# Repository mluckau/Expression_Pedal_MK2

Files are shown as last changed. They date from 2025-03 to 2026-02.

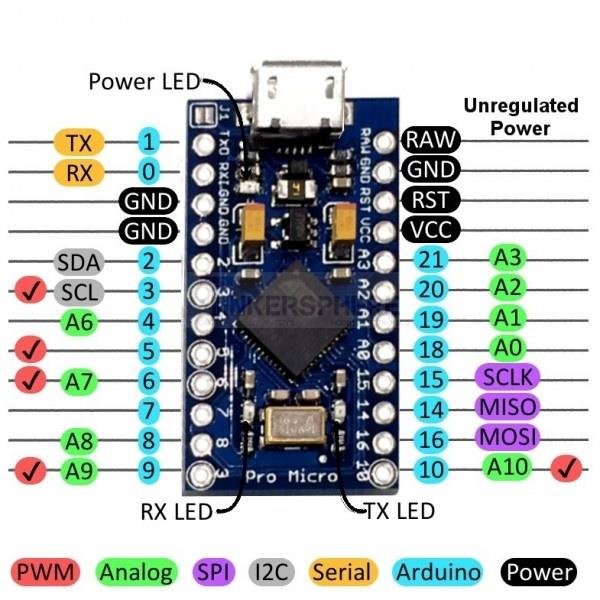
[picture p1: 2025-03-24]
Expression Pedal USB-Adapter/Arduino-Pro-Micro-connections-pinouts.png

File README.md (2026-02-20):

# Expression Pedal MK2 – USB-MIDI Adapter

Ein hochpräziser, zweikanaliger USB-MIDI-Adapter für Expression-Pedale, basierend auf dem Arduino Pro Micro (ATmega32U4). Er wandelt analoge Widerstandswerte herkömmlicher Expression-Pedale in MIDI-Control-Change (CC) Befehle um.

## Features
* **Dual Channel:** Unterstützt zwei unabhängige Expression-Pedale.
* **Plug & Play:** Wird als Standard MIDI-Gerät ("InkoTech Exp MK1") erkannt.
* **Auto-Kalibrierung:** Lernt automatisch den Bewegungsbereich des Pedals.
* **EEPROM-Speicher:** Behält die Kalibrierung auch nach dem Ausstecken bei.
* **Präzisions-Filter:** EMA-Filterung und Hysterese eliminieren Jitter und "Zappeln" der MIDI-Werte komplett.
* **Hardware-Erkennung:** Automatische Erkennung, ob ein Pedal eingesteckt ist (via Schaltbuchsen).
* **Status-LED:** Visuelles Feedback über die Onboard-TX-LED bei MIDI-Aktivität.

## Hardware & Stückliste (BOM)
| Komponente | Anzahl | Beschreibung |
| :--- | :--- | :--- |
| **Arduino Pro Micro** | 1 | ATmega32U4 (5V/16MHz) mit USB-C |
| **Klinkenbuchse 6,35mm** | 2 | TRS (Stereo) mit Schaltkontakt (z.B. REAN NYS216G) |
| **Gehäuse** | 1 | 3D-gedruckt (siehe `Gehäuse/` Ordner) |
| **USB-C Kabel** | 1 | Zur Verbindung mit dem PC |

## Schaltplan (Pinbelegung)
Die Verdrahtung erfolgt direkt am Arduino Pro Micro:

### Expression Pedal 1 (TRS Buchse)
* **Sleeve (S):** GND
* **Ring (R):** 5V (VCC)
* **Tip (T):** Pin **A0** (Wiper des Potis)
* **Schaltkontakt:** Pin **5** (Zieht Pin auf HIGH/LOW zur Erkennung)

### Expression Pedal 2 (TRS Buchse)
* **Sleeve (S):** GND
* **Ring (R):** 5V (VCC)
* **Tip (T):** Pin **A2** (Wiper des Potis)
* **Schaltkontakt:** Pin **6** (Zieht Pin auf HIGH/LOW zur Erkennung)

## Software-Konfiguration
Das Projekt wird mit **PlatformIO** verwaltet.

### Wichtige Parameter in `src/main.cpp`:
* `ALPHA`: Glättungsfaktor (Standard: 0.15). Niedriger = glatter, Höher = schneller.
* `DEADZONE`: Puffer an den Endpunkten (Standard: 15), um sicher 0 und 127 zu erreichen.
* `HYSTERESIS`: Verhindert das Springen zwischen zwei MIDI-Werten (Standard: 0.6).
* `#define DEBUG`: Einkommentieren für Testausgaben im Seriellen Monitor (115200 Baud).

## Bedienung & Kalibrierung
1. Schließe den Adapter an den PC an.
2. Stecke dein Expression-Pedal ein.
3. **Erste Benutzung:** Bewege das Pedal einmal komplett von Anschlag zu Anschlag (Heel to Toe).
4. Der Adapter speichert diese Werte nach 30 Sekunden Stabilität im EEPROM.
5. In deiner DAW (Bitwig, Reaper, etc.) den "InkoTech Exp MK1" auswählen und per "MIDI Learn" zuweisen.

## Lizenz
Dieses Projekt ist Open Source. Viel Spaß beim Nachbauen!

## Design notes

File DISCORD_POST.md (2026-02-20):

# Expression-Pedal-Adapter MK2: DIY USB-MIDI Interface (Dual-Channel)

Moin Leute! 👋

Ich wollte euch mal mein neuestes DIY-Projekt vorstellen: Ein **Expression-Pedal-Adapter**, der herkömmliche analoge Pedale in hochpräzise USB-MIDI Controller verwandelt.

### Warum das Ganze?
Die meisten kommerziellen Adapter sind entweder zu teuer, nur einkanalig oder haben Probleme mit "zappelnden" MIDI-Werten (Jitter). Da ich zwei Pedale nutze, musste eine eigene Lösung her!

### Die Highlights (Features):
* **Dual-Channel:** Ich habe zwei Stereo-Klinkenbuchsen verbaut, man kann also zwei Pedale gleichzeitig nutzen (z.B. Wah-Wah und Volume).
* **Auto-Kalibrierung:** Kein mühsames Eintippen von Min/Max-Werten im Code. Einmal das Pedal komplett bewegen, fertig!
* **EEPROM-Gedächtnis:** Die Kalibrierung wird gespeichert. Einmal eingestellt, bleibt sie auch nach dem Ausstecken erhalten.
* **EMA-Filter & Hysterese:** Ich habe einen exponentiellen Filter eingebaut, der das analoge Rauschen der Potis komplett eliminiert. Die MIDI-Werte sind absolut stabil.
* **Hardware-Erkennung:** Das Gerät erkennt automatisch, ob ein Pedal eingesteckt ist (via Schaltkontakt in der Buchse).

### Die Technik:
* **Controller:** Arduino Pro Micro (ATmega32U4) für native USB-MIDI Unterstützung.
* **Gehäuse:** 3D-gedruckt (FreeCAD Design), kompakt und stabil.
* **Code:** Objektorientiertes C++ mit PlatformIO.

### Was ich gelernt habe:
Besonders knifflig war das "Übersprechen" (Crosstalk) zwischen den analogen Eingängen des Arduinos. Ich habe das im Code durch einen "Double-Reading-Fix" gelöst, jetzt sind die Kanäle komplett isoliert.

Ich bin mit dem Ergebnis super zufrieden, die Latenz ist minimal und es fühlt sich in der DAW (Bitwig Studio / Manjaro Linux) richtig "snappy" an.

Falls jemand Interesse am Nachbau hat oder Fragen zum Code/Schaltplan hat, haut einfach in die Tasten! 🎸🎹

[Link zum GitHub Repository / Bilder / Video - Platzhalter]

Beste Grüße,
Michael

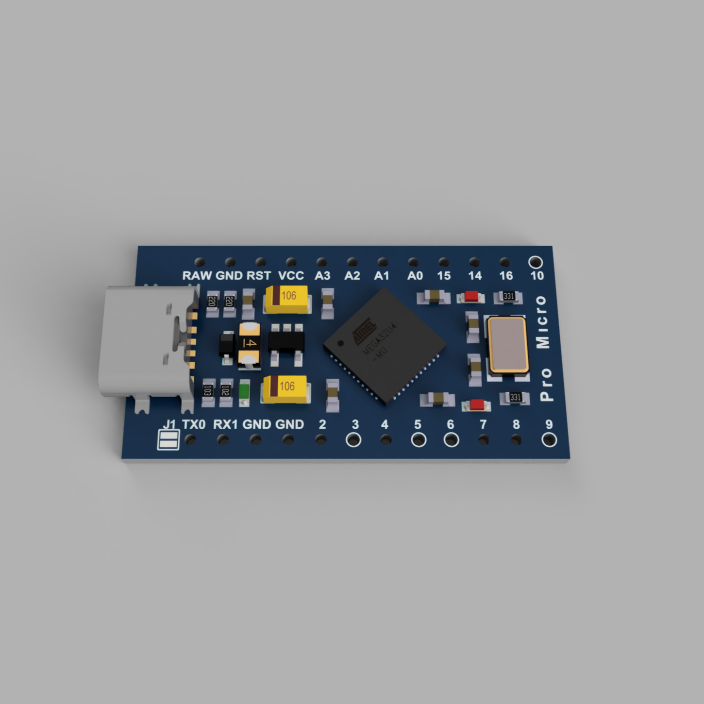
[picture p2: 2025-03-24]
Gehäuse/Models/Arduino_Pro_Micro_USB_Type_C_v1_2023-Jun-13_05-59-24PM-000_CustomizedView47374011633.png

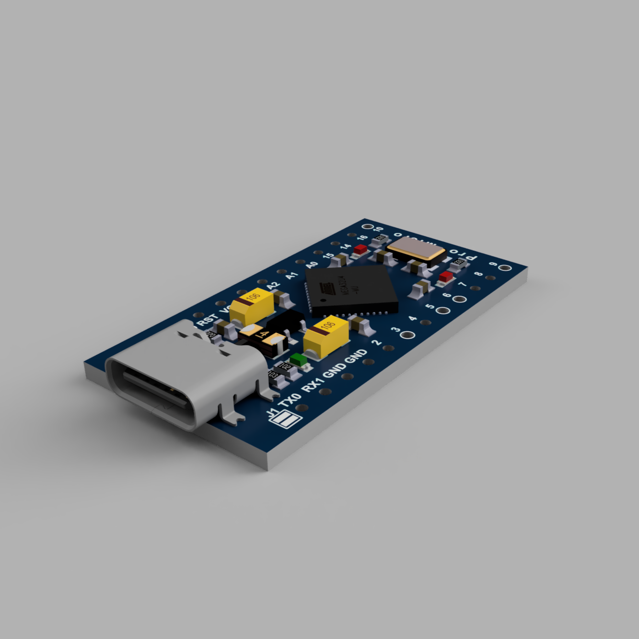
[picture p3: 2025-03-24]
Gehäuse/Models/Arduino_Pro_Micro_USB_Type_C_v1_2023-Jun-13_05-58-19PM-000_CustomizedView2097057146.png

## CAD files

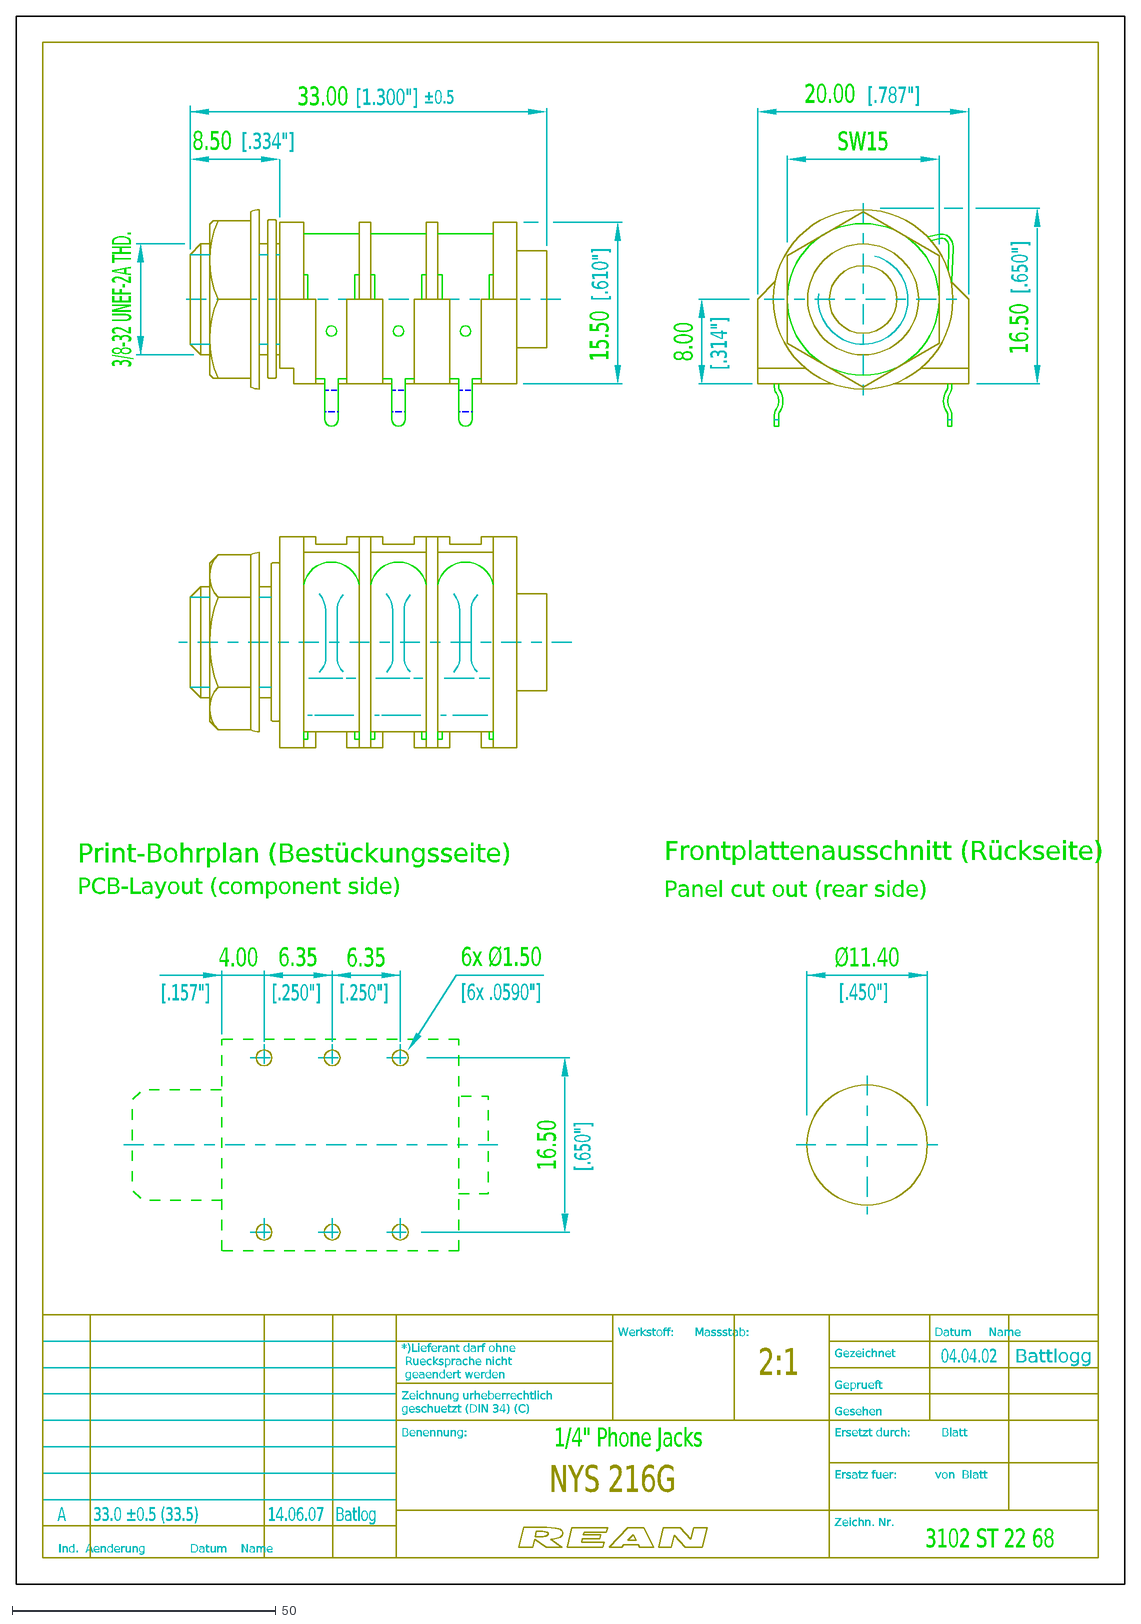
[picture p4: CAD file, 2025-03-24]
Expression Pedal USB-Adapter/nys-216g-1.dxf
Print-Bohrplan (Bestückungsseite)
PCB-Layout (component side)
4.00
[.157"]
[.250"]
6.35
Frontplattenausschnitt (Rückseite)
Panel cut out (rear side)
16.50
[.650"]
6x Ø1.50
[6x .0590"]
[.450"]
Ø11.40
3/8-32 UNEF-2A THD.
[.334"]
8.50
15.50
8.00
[.314"]
[.610"]
SW15
20.00
[.787"]
Battlogg
04.04.02
NYS 216G
1/4" Phone Jacks
3102 ST 22 68
2:1
A
33.0 ±0.5 (33.5)
14.06.07
Batlog
Zeichn. Nr.
Ersetzt durch: Blatt
Gezeichnet
Gesehen
Datum Name
Werkstoff: Massstab:
Benennung:
*)Lieferant darf ohne
Ruecksprache nicht
geaendert werden
Zeichnung urheberrechtlich
geschuetzt (DIN 34) (C)
Geprueft
Ersatz fuer: von Blatt
Ind. Aenderung Datum Name
33.00
[1.300"]
±0.5

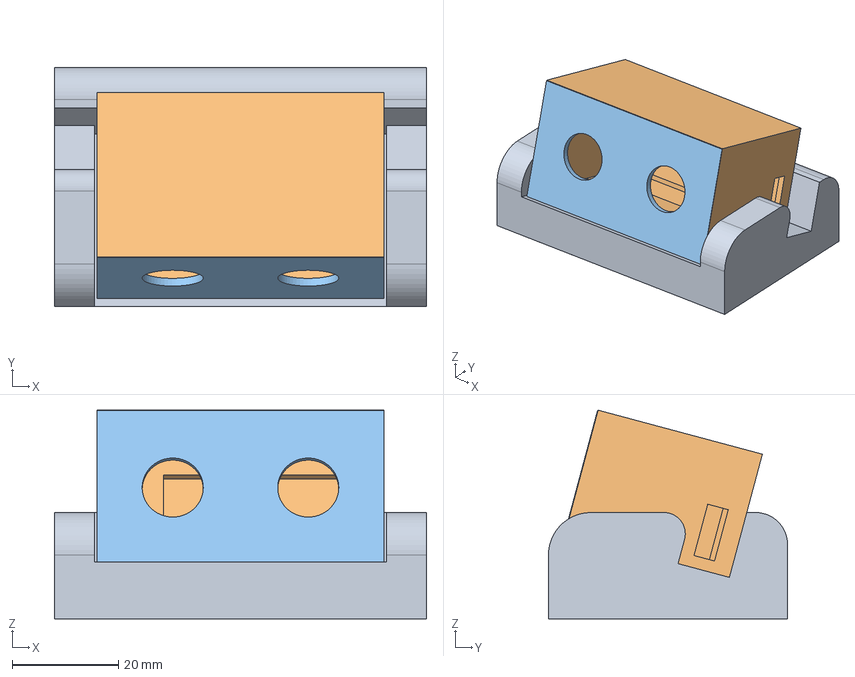
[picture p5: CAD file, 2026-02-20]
Gehäuse/Gehaeuse.FCStd
70.0 x 45.0 x 39.3 mm
Fuss
Expressionpedal Korpus
Deckel

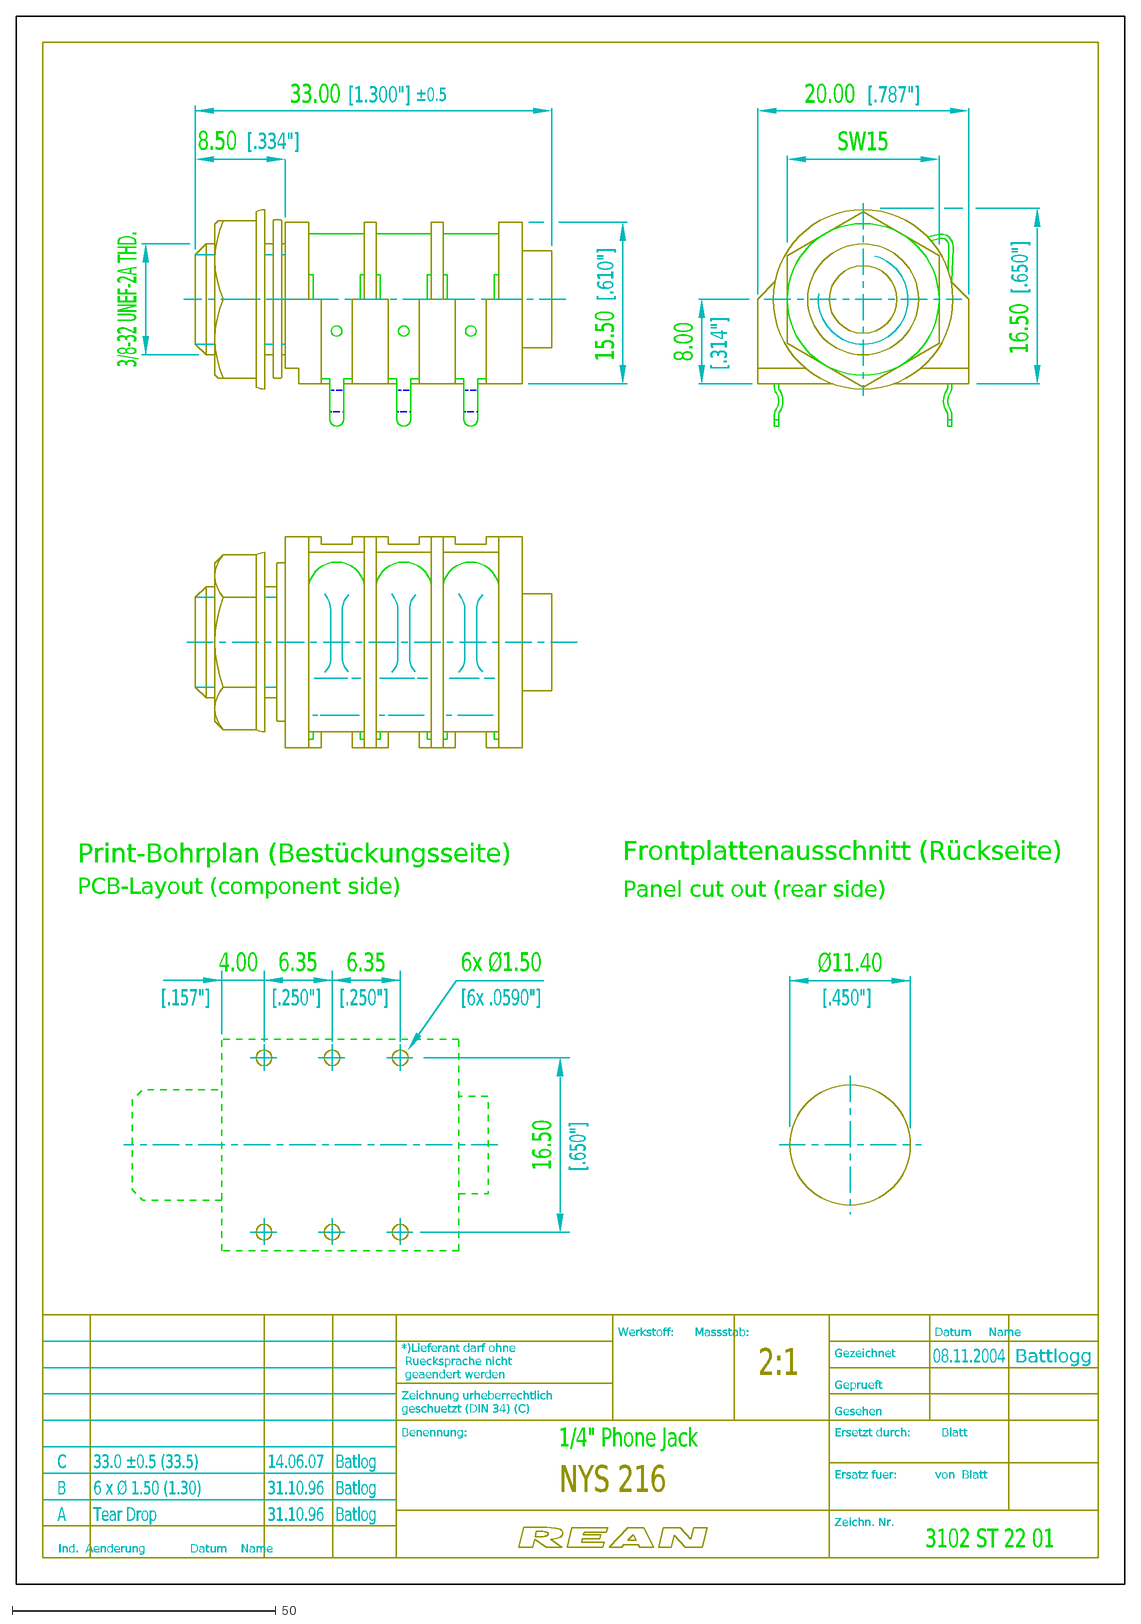
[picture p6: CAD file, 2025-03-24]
Gehäuse/Models/nys-216-1.dxf
8.50
33.00
20.00
8.00
15.50
3/8-32 UNEF-2A THD.
[1.300"]
[.334"]
[.787"]
[.314"]
[.610"]
[.650"]
16.50
6.35
[.250"]
[.157"]
4.00
[6x .0590"]
6x Ø1.50
Ø11.40
[.450"]
SW15
PCB-Layout (component side)
Print-Bohrplan (Bestückungsseite)
Panel cut out (rear side)
Frontplattenausschnitt (Rückseite)
Battlogg
08.11.2004
NYS 216
1/4" Phone Jack
3102 ST 22 01
2:1
A
Tear Drop
31.10.96
Batlog
B
6 x Ø 1.50 (1.30)
C
33.0 ±0.5 (33.5)
14.06.07
Zeichn. Nr.
Ersetzt durch: Blatt
Gezeichnet
Gesehen
Datum Name
Werkstoff: Massstab:
Benennung:
*)Lieferant darf ohne
Ruecksprache nicht
geaendert werden
Zeichnung urheberrechtlich
geschuetzt (DIN 34) (C)
Geprueft
Ersatz fuer: von Blatt
Ind. Aenderung Datum Name
±0.5

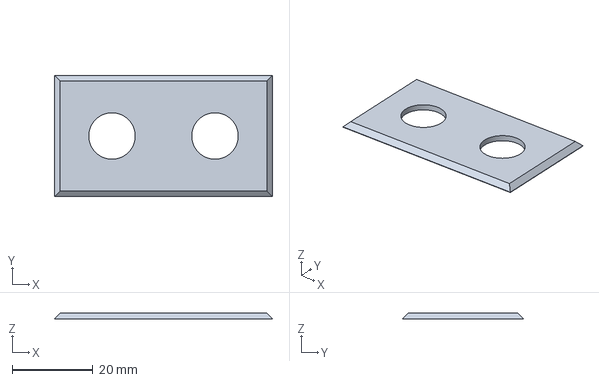
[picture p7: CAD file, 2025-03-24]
Gehäuse/Gehaeuse-Deckel.3mf
54.0 x 30.0 x 1.50 mm

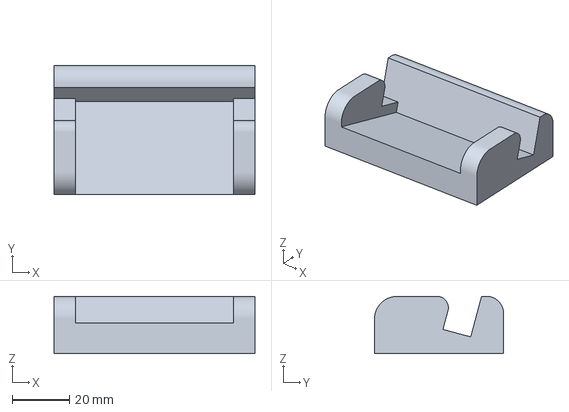
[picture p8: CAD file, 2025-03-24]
Gehäuse/Gehaeuse-Fuss.3mf
70.0 x 45.0 x 20.0 mm

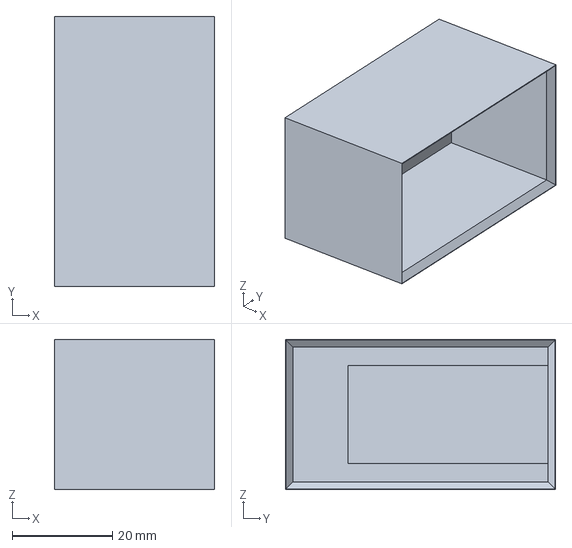
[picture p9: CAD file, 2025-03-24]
Gehäuse/Gehaeuse-Expressionpedal Korpus.3mf
32.0 x 54.0 x 30.0 mm

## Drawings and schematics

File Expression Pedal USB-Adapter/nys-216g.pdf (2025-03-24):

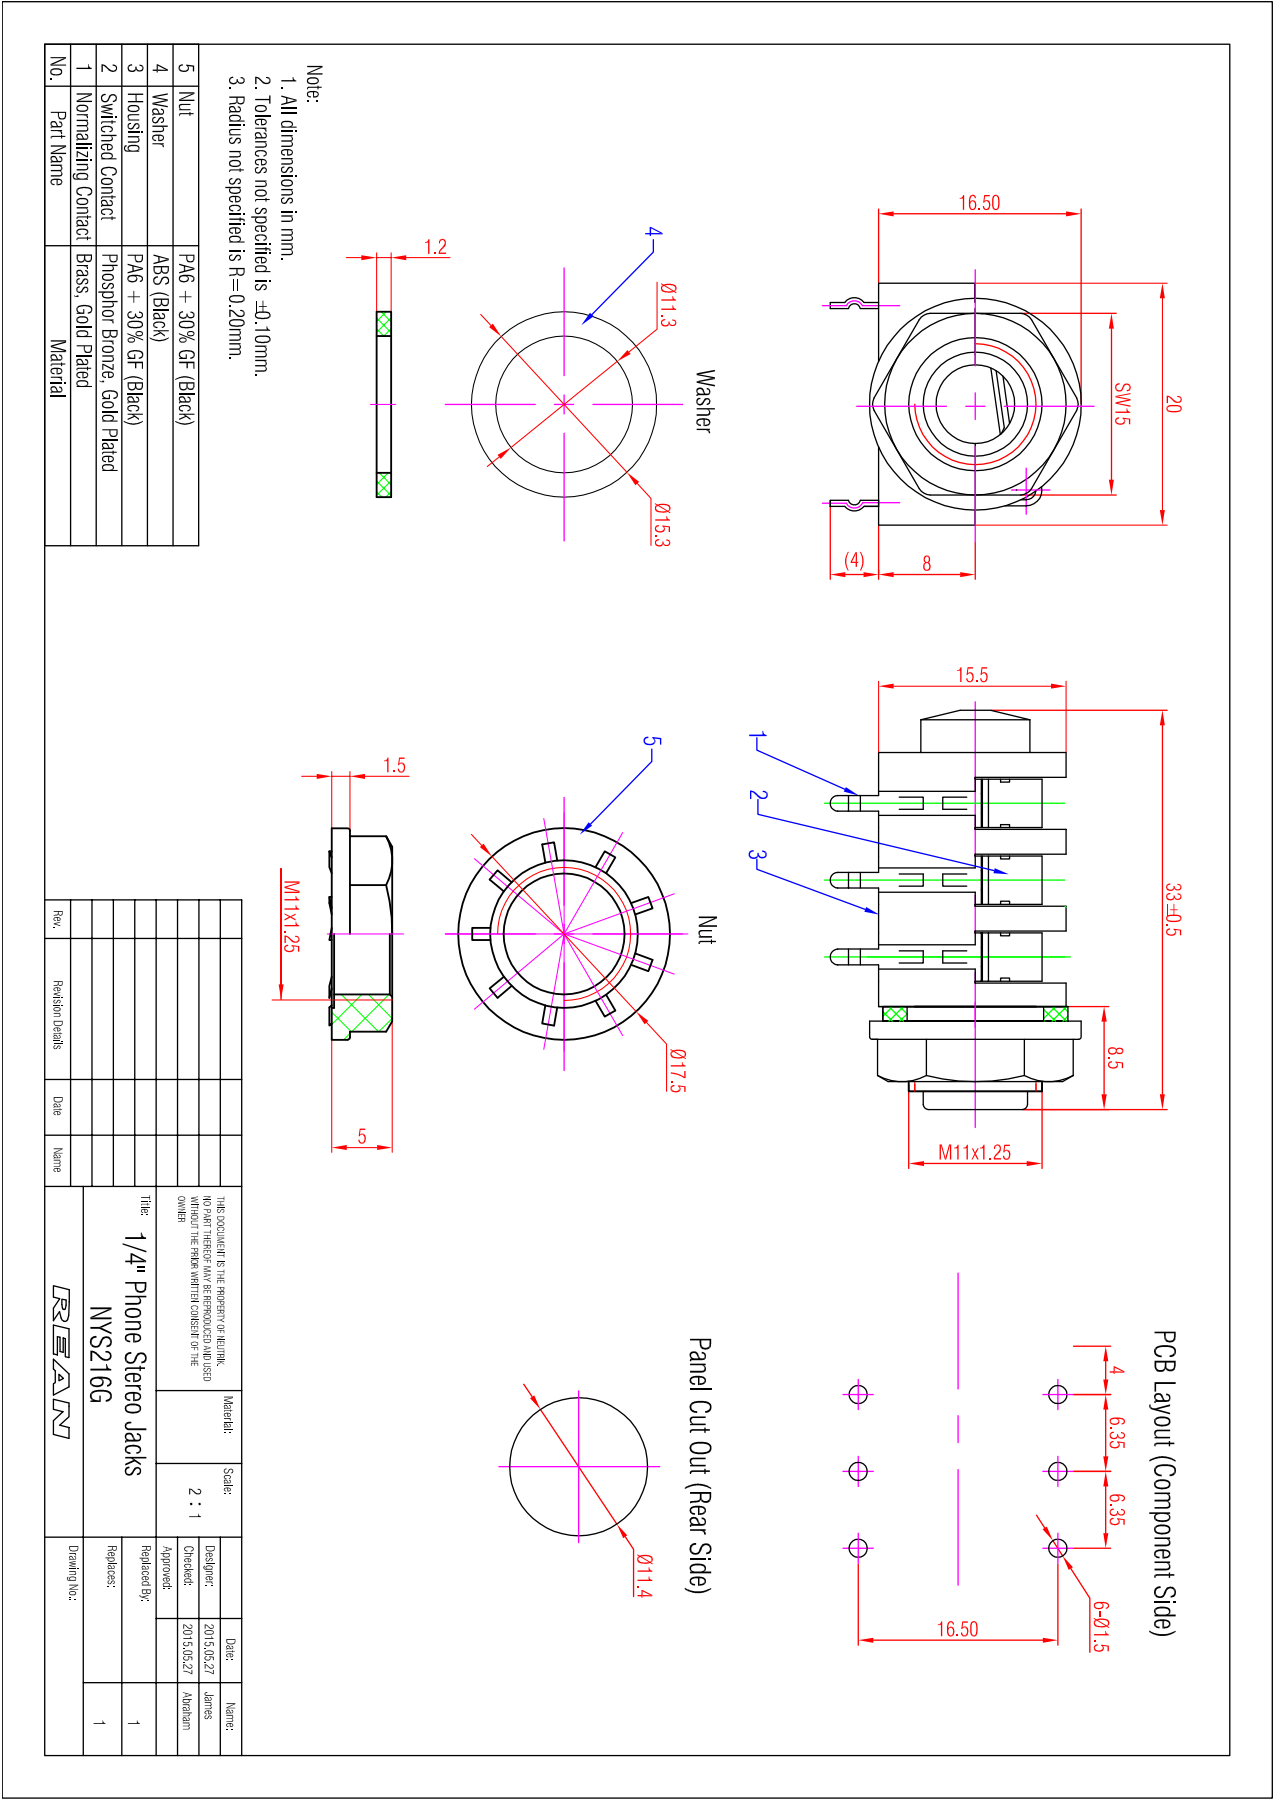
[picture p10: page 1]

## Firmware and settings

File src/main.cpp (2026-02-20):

#include <Arduino.h>
#include <MIDIUSB.h>
#include <EEPROM.h>

// --- KONFIGURATION ---
#define DEBUG               // Auskommentieren für maximale Performance im Betrieb
#define EEPROM_VERSION 1    // Erhöhen, um EEPROM-Daten zurückzusetzen
#define SAVE_INTERVAL 30000 // Alle 30 Sek. Kalibrierung speichern (schont EEPROM)

/**
 * ExpressionPedal Klasse (Final Polish Version)
 */
class ExpressionPedal {
  private:
    uint8_t _analogPin, _checkPin, _ccNumber, _midiChannel;
    float _smoothedValue;
    int _minVal, _maxVal;
    int _lastSentMidiValue;
    int _eepromAddr;
    unsigned long _lastSaveTime;
    bool _needsSave;

    const float _alpha = 0.15;
    const int _deadZone = 15;
    const float _hysteresis = 0.6; // Schwellenwert für Wertänderung

  public:
    ExpressionPedal(uint8_t analogPin, uint8_t checkPin, uint8_t cc, int eepromAddr, uint8_t channel = 1)
      : _analogPin(analogPin), _checkPin(checkPin), _ccNumber(cc), _midiChannel(channel),
        _smoothedValue(0), _minVal(1023), _maxVal(0), _lastSentMidiValue(-1),
        _eepromAddr(eepromAddr), _lastSaveTime(0), _needsSave(false) {}

    void begin() {
      pinMode(_checkPin, INPUT_PULLUP);
      loadCalibration();
      _smoothedValue = analogRead(_analogPin);
    }

    void update() {
      if (digitalRead(_checkPin) == LOW) return;

      analogRead(_analogPin); // Double-Reading Fix
      int raw = analogRead(_analogPin);

      // 1. Dynamische Auto-Kalibrierung
      bool rangeChanged = false;
      if (raw < _minVal) { _minVal = raw; rangeChanged = true; }
      if (raw > _maxVal) { _maxVal = raw; rangeChanged = true; }
      
      if (rangeChanged) {
        _needsSave = true;
        _lastSaveTime = millis();
      }

      // 2. Glättung
      _smoothedValue = (_alpha * raw) + ((1.0 - _alpha) * _smoothedValue);

      // 3. Mapping mit Hysterese & Totzonen
      if (_maxVal > _minVal + (_deadZone * 2)) {
        float mapped = mapFloat(_smoothedValue, _minVal + _deadZone, _maxVal - _deadZone, 0.0, 127.0);
        int currentMidiValue = (int)constrain(mapped, 0, 127);

        // Hysterese: Nur senden, wenn die Änderung signifikant ist oder wir an den Enden sind
        if (currentMidiValue != _lastSentMidiValue) {
          float diff = abs(mapped - (float)_lastSentMidiValue);
          if (diff >= _hysteresis || currentMidiValue == 0 || currentMidiValue == 127) {
            sendMidi(currentMidiValue);
            _lastSentMidiValue = currentMidiValue;
          }
        }
      }

      // 4. Periodisches Speichern im EEPROM (schont Schreibzyklen)
      if (_needsSave && (millis() - _lastSaveTime > SAVE_INTERVAL)) {
        saveCalibration();
      }
    }

  private:
    float mapFloat(float x, float in_min, float in_max, float out_min, float out_max) {
      return (x - in_min) * (out_max - out_min) / (in_max - in_min) + out_min;
    }

    void sendMidi(uint8_t value) {
      TXLED1;
      midiEventPacket_t event = {0x0B, (uint8_t)(0xB0 | (_midiChannel - 1)), _ccNumber, value};
      MidiUSB.sendMIDI(event);
      MidiUSB.flush();
      TXLED0;

#ifdef DEBUG
      Serial.print("Pedal (CC "); Serial.print(_ccNumber);
      Serial.print("): "); Serial.println(value);
#endif
    }

    void saveCalibration() {
      EEPROM.put(_eepromAddr, _minVal);
      EEPROM.put(_eepromAddr + sizeof(int), _maxVal);
      _needsSave = false;
#ifdef DEBUG
      Serial.println("-> Kalibrierung im EEPROM gespeichert.");
#endif
    }

    void loadCalibration() {
      int m, x;
      EEPROM.get(_eepromAddr, m);
      EEPROM.get(_eepromAddr + sizeof(int), x);
      
      // Validierung der Daten (wenn EEPROM leer ist, stehen dort oft 0 oder -1)
      if (m >= 0 && m < 1023 && x > 0 && x <= 1023 && x > m) {
        _minVal = m;
        _maxVal = x;
#ifdef DEBUG
        Serial.print("Kalibrierung geladen für CC "); Serial.print(_ccNumber);
        Serial.print(": "); Serial.print(_minVal); Serial.print("-"); Serial.println(_maxVal);
#endif
      }
    }
};

// --- INSTANZEN ---
// Adressen: 0-3 (Version), 10-13 (Pedal1 Min/Max), 20-23 (Pedal2 Min/Max)
ExpressionPedal pedal1(A0, 5, 11, 10, 1);
ExpressionPedal pedal2(A2, 6, 16, 20, 1);

unsigned long lastUpdate = 0;
const unsigned long UPDATE_INTERVAL_MS = 5;

void setup() {
#ifdef DEBUG
  Serial.begin(115200);
#endif
  
  // EEPROM Version Check (Reset wenn Version sich ändert)
  if (EEPROM.read(0) != EEPROM_VERSION) {
    for (int i = 0 ; i < EEPROM.length() ; i++) EEPROM.write(i, 0xFF);
    EEPROM.write(0, EEPROM_VERSION);
  }

  pedal1.begin();
  pedal2.begin();
  TXLED0;
  RXLED0;
}

void loop() {
  unsigned long now = millis();
  if (now - lastUpdate >= UPDATE_INTERVAL_MS) {
    lastUpdate = now;
    pedal1.update();
    pedal2.update();
  }
}

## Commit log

2025-03-24 gehäuse
    [Gehaeuse-Deckel.3mf, Gehaeuse-Expressionpedal Korpus.3mf, Gehaeuse-Fuss.3mf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]
2025-03-24 KiCAD und Pio-Board Definition
    [EXP_P_USB_Adapter.kicad_pcb, EXP_P_USB_Adapter.kicad_sch, nys-216g-1.dxf]
2026-02-20 Refactor expression pedal logic: OOP, EMA filtering, and auto-calibration
    [Gehaeuse.FCStd]
